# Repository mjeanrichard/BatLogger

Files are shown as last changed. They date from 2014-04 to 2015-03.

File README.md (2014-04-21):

#BatLogger

An Adruino based BatLogger with evaluation Software.

##Circuit
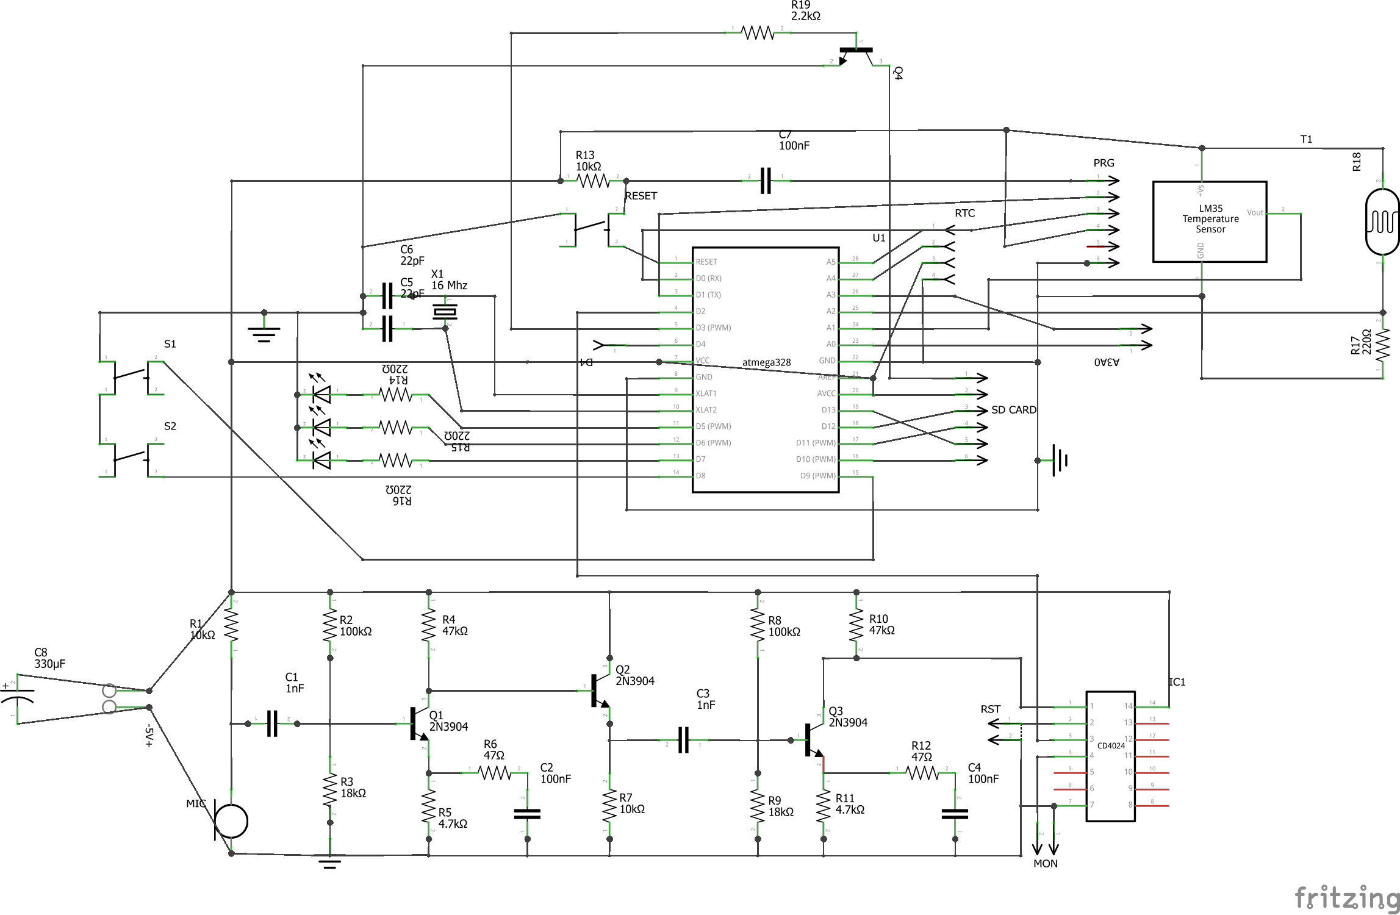
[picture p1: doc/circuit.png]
Current Circuit

###PCB (Fritzing)
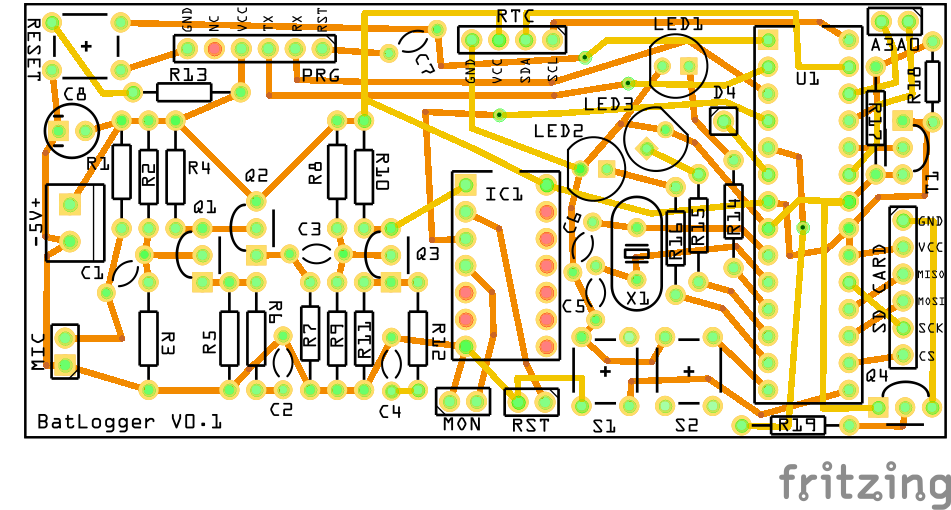
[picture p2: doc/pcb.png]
Current PCB Layout


##Links
* Circuit Help http://forum.allaboutcircuits.com/showthread.php?t=96364
* ArduBat http://home.earthlink.net/~bat-detector/ArduBat/

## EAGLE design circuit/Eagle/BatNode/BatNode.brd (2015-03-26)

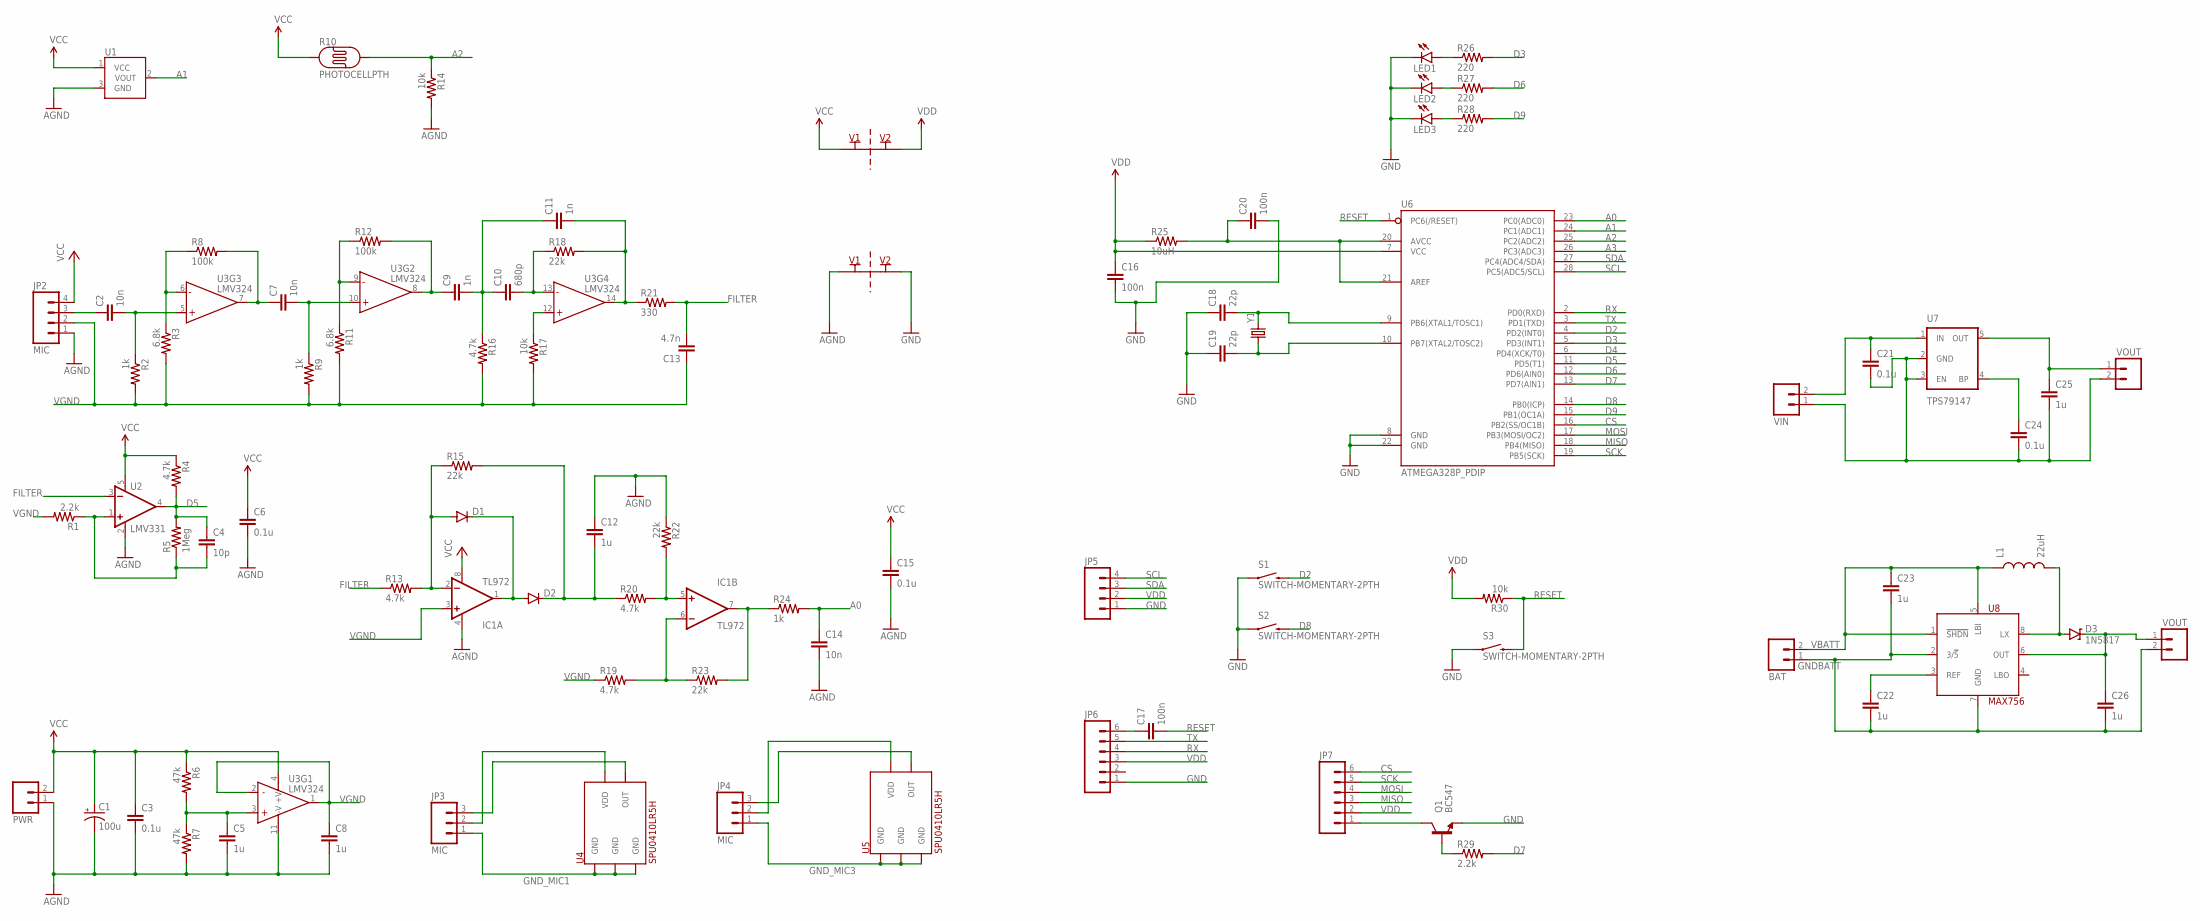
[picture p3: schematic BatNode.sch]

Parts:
C1: 100u; CPOL-RADIAL-100UF-25V
C2, C7, C14: 10n; C025-030X050
C3, C6, C15, C21, C24: 0.1u; 0805
C4: 10p; C025-030X050
C5, C8: 1u; 0805
C9, C11: 1n; C025-030X050
C10: 680p; C025-030X050
C12, C22, C23, C25, C26: 1u; C025-030X050
C13: 4.7n; C025-030X050
C16, C17, C20: 100n; 0805
C18, C19: 22p; CAP-PTH-SMALL
D1, D2: DIODE1N4148; DIODE-1N4148
D3: 1N5817; DIODE-ZENER
IC1: TL972; SO08
JP1: PWR; 1X02_LOCK
JP2: MIC; 1X04
JP3, JP4: MIC; 1X03_LOCK
JP5: M04LOCK; 1X04_LOCK
JP6, JP7: M06LOCK; 1X06_LOCK
JP8: BAT; 1X02_LOCK
JP9: VIN; 1X02_LOCK
JP10, JP11: VOUT; 1X02_LOCK
L1: 22uH; C2020
LED1, LED2, LED3: LED5MM
Q1: BC547; TO-92-AMMO
R1, R29: 2.2k; AXIAL-0.3
R2, R9, R24: 1k; AXIAL-0.3
R3, R11: 6.8k; AXIAL-0.3
R4, R13, R16, R19, R20: 4.7k; AXIAL-0.3
R5: 1Meg; AXIAL-0.3
R6, R7: 47k; AXIAL-0.3
R8, R12: 100k; AXIAL-0.3
R10: PHOTOCELLPTH; PHOTOCELL
R14, R17, R30: 10k; AXIAL-0.3
R15, R18, R22, R23: 22k; AXIAL-0.3
R21: 330; AXIAL-0.3
R25: 10uH; AXIAL-0.3
R26, R27, R28: 220; AXIAL-0.3
S1, S2, S3: SWITCH-MOMENTARY-2PTH; TACTILE-PTH
U1: TMP36GT9; TO-92
U2: LMV331; SOT23-5
U3: LMV324; SO014
U4, U5: SPU0410LR5H
U6: ATMEGA328P_PDIP; DIL28-3
U7: TPS79147; SOT23-5
U8: MAX756; SO08
X11, X12: SUPPLY_CONNECT; 2PT_GND_TIE
Y1: CRYSTALHC49UV; HC49U-V

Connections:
A0: C14.1, R24.P$2 (2), U6.23 (PC0(ADC0))
A1: U1.2 (VOUT), U6.24 (PC1(ADC1))
A2: R10.2, R14.P$1 (1), U6.25 (PC2(ADC2))
A3: U6.26 (PC3(ADC3))
AGND: C1.2 (-), C3.2, C5.2, C6.2, C8.2, C12.1, C14.2, C15.2, IC1.4 (V-), JP1.1, JP2.1, R7.P$2 (2), R14.P$2 (2), R22.P$1 (1), U1.3 (GND), U2.2 (V-), U3.11 (-V), X12.P$1
CS: JP7.6, U6.16 (PB2(SS/OC1B))
D2: S1.3 (2), U6.4 (PD2(INT0))
D3: R26.P$2 (2), U6.5 (PD3(INT1))
D4: U6.6 (PD4(XCK/T0))
D5: C4.1, R4.P$2 (2), R5.P$2 (2), U2.4 (OUT), U6.11 (PD5(T1))
D6: R27.P$2 (2), U6.12 (PD6(AIN0))
D7: R29.P$2 (2), U6.13 (PD7(AIN1))
D8: S2.3 (2), U6.14 (PB0(ICP))
D9: R28.P$2 (2), U6.15 (PB1(OC1A))
FILTER: C13.2, R13.P$1 (1), R21.P$2 (2), U2.3 (-IN)
GND: C16.2, C18.1, C19.1, C20.2, JP5.1, JP6.1, LED1.K (C), LED2.K (C), LED3.K (C), Q1.3 (E), S1.1, S2.1, S3.1, U6.8 (GND), U6.22 (GND), X12.P$2
GNDBATT: C22.2, C23.2, C26.2, JP8.1, JP11.2, U8.2 (3/!5), U8.7 (GND)
GNDIN: C21.2, C24.2, C25.2, JP9.1, JP10.2, U7.2 (GND), U7.3 (EN)
GND_MIC1: JP3.1, U4.2 (GND), U4.3 (GND), U4.5 (GND)
GND_MIC3: JP4.1, U5.2 (GND), U5.3 (GND), U5.5 (GND)
MISO: JP7.3, U6.18 (PB4(MISO))
MOSI: JP7.4, U6.17 (PB3(MOSI/OC2))
unnamed: C5.1, R6.P$2 (2), R7.P$1 (1), U3.3 (+IN)
unnamed: C2.2, R2.P$1 (1), U3.5 (+IN)
unnamed: R3.P$1 (1), R8.P$1 (1), U3.6 (-IN)
unnamed: C7.1, R8.P$2 (2), U3.7 (OUT)
unnamed: C7.2, R9.P$1 (1), U3.10 (+IN)
unnamed: C9.1, R12.P$2 (2), U3.8 (OUT)
unnamed: R11.P$1 (1), R12.P$1 (1), U3.9 (-IN)
unnamed: C9.2, C10.1, C11.1, R16.P$1 (1)
unnamed: R17.P$1 (1), U3.12 (+IN)
unnamed: C10.2, R18.P$1 (1), U3.13 (-IN)
unnamed: C2.1, JP2.3
unnamed: C4.2, R1.P$1 (1), R5.P$1 (1), U2.1 (+IN)
unnamed: C17.1, JP6.6
unnamed: JP3.2, U4.4 (VDD)
unnamed: JP3.3, U4.1 (OUT)
unnamed: C18.2, U6.9 (PB6(XTAL1/TOSC1)), Y1.2
unnamed: C19.2, U6.10 (PB7(XTAL2/TOSC2)), Y1.1
unnamed: JP7.1, Q1.1 (C)
unnamed: C20.1, R25.P$2 (2), U6.20 (AVCC), U6.21 (AREF)
unnamed: JP4.2, U5.4 (VDD)
unnamed: Q1.2 (B), R29.P$1 (1)
unnamed: LED1.A, R26.P$1 (1)
unnamed: LED2.A, R27.P$1 (1)
unnamed: LED3.A, R28.P$1 (1)
unnamed: D3.P$2 (A), L1.P$2 (2), U8.8 (LX)
unnamed: C24.1, U7.4 (BP)
unnamed: D1.A, IC1.2 (-IN), R13.P$2 (2), R15.P$1 (1)
unnamed: JP4.3, U5.1 (OUT)
unnamed: D1.C, D2.A, IC1.1 (OUT)
unnamed: IC1.5 (+IN), R20.P$2 (2), R22.P$2 (2)
unnamed: C12.2, D2.C, R15.P$2 (2), R20.P$1 (1)
unnamed: IC1.6 (-IN), R19.P$2 (2), R23.P$1 (1)
unnamed: C26.1, D3.P$1 (C), JP11.1, U8.6 (OUT)
unnamed: C22.1, U8.3 (REF)
RESET: C17.2, R30.P$1 (1), S3.3 (2), U6.1 (PC6(/RESET))
RX: JP6.4, U6.2 (PD0(RXD))
SCK: JP7.5, U6.19 (PB5(SCK))
SCL: JP5.4, U6.28 (PC5(ADC5/SCL))
SDA: JP5.3, U6.27 (PC4(ADC4/SDA))
TX: JP6.5, U6.3 (PD1(TXD))
VBATT: C23.1, JP8.2, L1.P$1 (1), U8.1 (!SHDN), U8.5 (LBI)
VCC: C1.1 (+), C3.1, C6.1, C15.1, IC1.8 (V+), JP1.2, JP2.4, R4.P$1 (1), R6.P$1 (1), R10.1, U1.1 (VCC), U2.5 (V+), U3.4 (+V), X11.P$1
VDD: C16.1, JP5.2, JP6.3, JP7.2, R25.P$1 (1), R30.P$2 (2), U6.7 (VCC), X11.P$2
VGND: C8.1, C13.1, IC1.3 (+IN), JP2.2, R1.P$2 (2), R2.P$2 (2), R3.P$2 (2), R9.P$2 (2), R11.P$2 (2), R16.P$2 (2), R17.P$2 (2), R19.P$1 (1), U3.1 (OUT), U3.2 (-IN)
VIN: C21.1, JP9.2, U7.1 (IN)
VOUT: C25.1, JP10.1, U7.5 (OUT)
X1: IC1.7 (OUT), R23.P$2 (2), R24.P$1 (1)
XXX: C11.2, R18.P$2 (2), R21.P$1 (1), U3.14 (OUT)

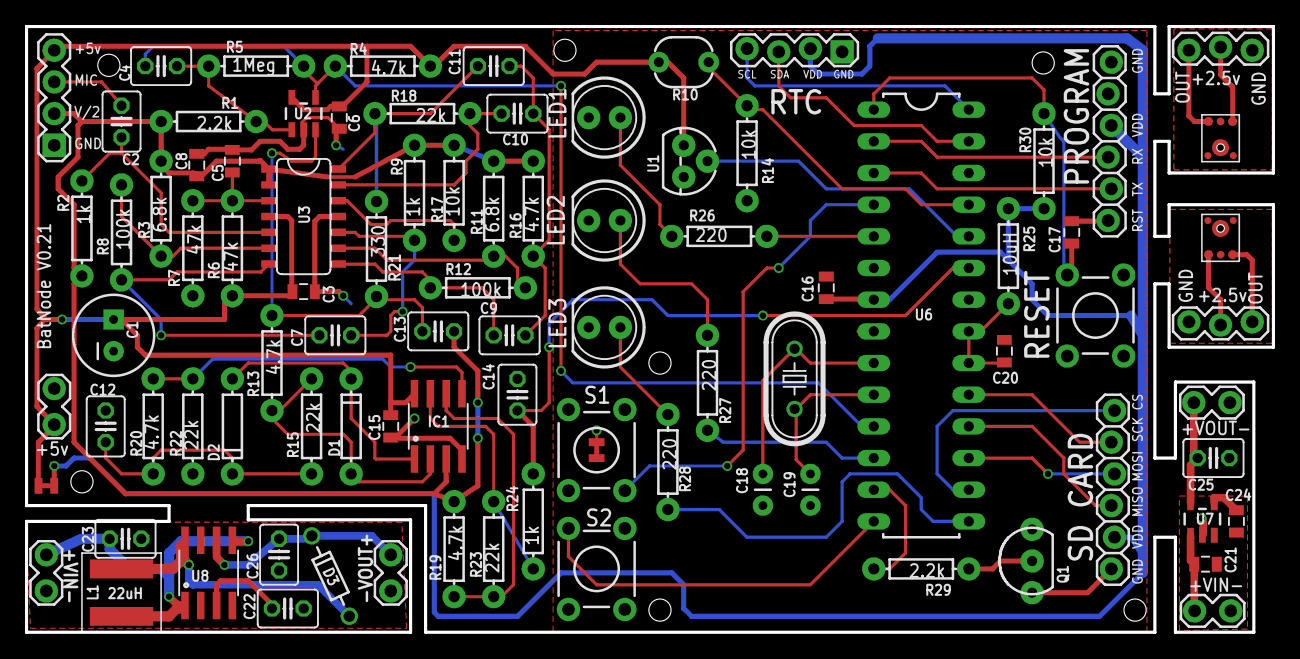
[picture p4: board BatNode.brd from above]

Board: 2 copper layers, 100.0 x 48.6 mm, 90 parts (0 on the bottom side), 68 nets.

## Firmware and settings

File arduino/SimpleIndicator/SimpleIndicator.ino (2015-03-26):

#include <SdFat.h>
SdFat sd;

const int PIN_LED_GREEN = 3;
const int PIN_LED_YELLOW = 6;
const int PIN_LED_RED = 9;

const int SDShieldSwitchPin = 7;
const int SDPin = 10;

// Anzahl Datensaetze die im speicher gehalten werden, bevor auf die Karte geschrieben wird.
const byte LogBufferSize = 100;
//index auf die aktuelle Buffer position
byte index = 0;

/*unsigned long pulseStore[LogBufferSize];
unsigned long durationStore[LogBufferSize];
unsigned long startTimeStore[LogBufferSize];
unsigned int maxFreqStore[LogBufferSize];
*/


unsigned int timeSeries[LogBufferSize];
unsigned int pulseSeries[LogBufferSize];
unsigned int loudSeries[LogBufferSize];
int seriesIndex = 0;


char filename[] = "LOG--.CSV";


unsigned long readCounter(){
	unsigned int value = 0;
	unsigned int of = 0;

	TCCR1B = 0;
	value = TCNT1;
	of = TIFR1 & (1 << TOV1);
	TCNT1 = 0;
	TIFR1 = (1 << TOV1);
	TCCR1B = (1 << CS12) | (1 << CS11) | (1 << CS10);
	if (of){
		return value + 65536UL;
	}
	return value;
}

void initCounter()
{
	TCCR1B = 0;
	TCCR1A = 0;
	TCNT1 = 0;
	TIFR1 = (1 << TOV1);
	TIMSK1 = 0;

	// External clock source on T1 pin. Clock on rising edge.
	TCCR1B = (1 << CS12) | (1 << CS11) | (1 << CS10);
}


void setup()
{
	Serial.begin(57600);
  
	pinMode(PIN_LED_GREEN, OUTPUT);
	pinMode(PIN_LED_YELLOW, OUTPUT);
	pinMode(PIN_LED_RED, OUTPUT);

	pinMode(A0, INPUT);

	SdFile file = openLogFile();
	file.println("#StartUp completed");
	closeLogFile(file);

	initCounter();
}

void loop()
{
        readCounter();
	int led = 0;
        unsigned long startTime=micros();
        unsigned long lastTime=startTime;
        unsigned long sum=0;
        unsigned int maxFreqKhz=0;
        int loud=0;
        
 	while (true)
	{
		delayMicroseconds(1000);
		unsigned long val = readCounter();
                unsigned long time = micros();

                if (led > 0) {
                  digitalWrite(led, LOW);
                }
		led = 0;
                
                if (val < 10){
                  unsigned long diff = time - startTime;
                  if (sum > 0 && maxFreqKhz > 9 && diff > 5000){
                    //logData(sum, startTime, diff, maxFreqKhz, loud);
                    writeSeries();
                    //logSeries();
                  }
                  sum = 0;
                  maxFreqKhz = 0;
                  seriesIndex = 0;
                  lastTime=time;
                  startTime=time;
                  continue;
                }
                
                sum += val;
                unsigned long diff = time - startTime;
                unsigned int freqKhz = (sum * 1000) / diff;
                
                timeSeries[seriesIndex] = time-lastTime;
                pulseSeries[seriesIndex] = val;
                loudSeries[seriesIndex] = analogRead(A0);

                
                if (freqKhz > maxFreqKhz){
                  maxFreqKhz = freqKhz;
                }

                seriesIndex = (seriesIndex + 1) % LogBufferSize;
                lastTime=time;
	}
}

void logSeries(){
  digitalWrite(PIN_LED_RED, HIGH);
  Serial.println("------------------------------");
  for (int i = 0; i < seriesIndex && i < LogBufferSize; i++){
    Serial.print(i);
    Serial.print(';');
    Serial.print(timeSeries[i]);
    Serial.print(';');
    Serial.print(pulseSeries[i]);
    Serial.print(';');
    Serial.println(loudSeries[i]);
  }
  digitalWrite(PIN_LED_RED, LOW);
}

void writeSeries(){
  digitalWrite(PIN_LED_RED, HIGH);
  SdFile file = openLogFile();
  file.println("--------");
  for (int i = 0; i < seriesIndex && i < LogBufferSize; i++){
    file.print(i);
    file.print(';');
    file.print(timeSeries[i]);
    file.print(';');
    file.print(pulseSeries[i]);
    file.print(';');
    file.println(loudSeries[i]);
  }
  closeLogFile(file);
  digitalWrite(PIN_LED_RED, LOW);
}

// == Opens the Logfile (and initializes if new)
SdFile openLogFile(){
/*  digitalWrite(PIN_LED_RED, HIGH);
  digitalWrite(SDShieldSwitchPin, HIGH);
  delay(200);
*/
  if (!sd.begin(SDPin, SPI_FULL_SPEED)){
    Serial.println("SD-Init failed.");
  }

  SdFile logfile;
  if (!sd.exists(filename)) {
    logfile = initializeNewLog();
  } 
  else if (!logfile.open(filename, O_RDWR | O_CREAT | O_AT_END)) {
    Serial.println("SDOpen failed.");
  } 
  return logfile;
}

// == Closes LogFile and turns the LED and the SD Module off.
void closeLogFile(SdFile logfile)
{
  logfile.close();
  /*delay(200);
  digitalWrite(SDShieldSwitchPin, LOW);
  digitalWrite(PIN_LED_RED, LOW);*/
}

// == Initializese a new LogFile with Headers.
SdFile initializeNewLog()
{
  SdFile logfile;
  for (int i = 0; i < 100; i++) {
    filename[3] = i/10 + '0';
    filename[4] = i%10 + '0';
    if (!sd.exists(filename)) {
      if (!logfile.open(filename, O_RDWR | O_CREAT | O_AT_END)) {
        Serial.println("SDOpen (2) failed.");
      } 
      break;
    }
  }

  unsigned long nowMillis = millis();
  char buffer[150];

  sprintf_P(buffer, PSTR("#start time;pulses;duration;maxFreq"));
  logfile.println(buffer);
  return logfile;
}

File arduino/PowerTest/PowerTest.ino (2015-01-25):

const int chipSelect = 10;
const int sdEnable = 7;

int s1 = 2;
int s2 = 8;

int led1 = 3;
int led2 = 6;
int led3 = 9;

#include <SdFat.h>
SdFat sd;
SdFile myFile;

void setup() {
  pinMode(sdEnable, OUTPUT);
  
  pinMode(led1, OUTPUT);
  pinMode(led2, OUTPUT);
  pinMode(led3, OUTPUT);
  
  pinMode(s1, INPUT_PULLUP);
  pinMode(s2, INPUT_PULLUP);

  //digitalWrite(sdEnable, HIGH);

}

int test = 5;

void loop() {
  digitalWrite(led1, HIGH);
  while(digitalRead(s1)){}
  while(!digitalRead(s1)){}
  digitalWrite(led3, HIGH);
  delay(1000);

  digitalWrite(sdEnable, HIGH);
  delay(500);
  
  if (!sd.begin(chipSelect, SPI_HALF_SPEED)) sd.initErrorHalt();

  if (!myFile.open("test.txt", O_RDWR | O_CREAT | O_AT_END)) {
    sd.errorHalt("opening test.txt for write failed");
  }
  myFile.println("Test ");
  myFile.close();
  
  delay(200);
  digitalWrite(led3, LOW);
  digitalWrite(sdEnable, LOW);
  digitalWrite(led1, LOW);

  delay(5000);

  digitalWrite(led2, HIGH);
  while(digitalRead(s2)){}
  while(!digitalRead(s2)){}
  digitalWrite(led3, HIGH);
  delay(1000);

  digitalWrite(led3, LOW);
  digitalWrite(sdEnable, LOW);
  digitalWrite(led2, LOW);
  delay(5000);

  digitalWrite(led3, HIGH);
  delay(2000);
  digitalWrite(led3, LOW);
}

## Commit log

2014-04-20 Initial Checkin.
    [BatLogger.fzz]
2014-05-29 BatLogger V0.2 PCB
    [BatLogger.fzz]
2014-05-29 BatLogger V0.2 PCB (RTC Connector turned)
    [BatLogger.fzz]
2014-05-29 Arduino Skript an neue SDFat Library angepasst.
2014-06-16 BatLogger und Setup Solution hinzugefügt.
2014-06-16 Kleine Korrekturen am PCB
    [BatLogger.fzz]
2014-08-03 BatLogger auf Basis von Timer1
2014-08-05 PCB V0.3 (LM386)
    [BatLoggerLm386.fzz]
2014-08-08 PCB V0.3.1 (LM386)
    [BatLoggerLm386.fzz]
2015-01-25 Arduino-Code Archive
2015-01-25 BatNode v0.2
    [BatNode.brd, BatNode.sch]
2015-03-26 BatNode v0.21
    [BatNode.brd, BatNode.sch]

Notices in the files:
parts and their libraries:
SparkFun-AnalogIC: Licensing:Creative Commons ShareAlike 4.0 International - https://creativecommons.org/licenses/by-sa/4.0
